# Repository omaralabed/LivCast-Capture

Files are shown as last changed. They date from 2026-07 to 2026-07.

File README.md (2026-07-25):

# LivCast Capture

Compact **CM5** HDMI/SDI capture box for **Livcast-iOS** on iPhone.

Camera in → on-box preview → USB-C **network video** to phone. Bonding is a separate product (**LivCast Bond**).

## Locked I/O

| Port | Direction | Job |
|---|---|-----|
| SDI in | In | Camera (BNC) |
| HDMI in | In | Camera |
| Input select | Software | HDMI **or** SDI (dual CSI bridges) |
| HDMI out | Out | Playback / external monitor |
| SDI out | Out | Playback / SDI deck |
| USB-C (phone) | Data + charge | Network video → iPhone; **box charges phone** |
| USB-C (power) | In | PD: wall charger or adapter |
| D-Tap | In | Camera battery power |
| 3.5" LCD | On box | SPI preview via 40-pin GPIO (Hosyond 480×320) |

## Locked ingest (best quality)

**Dual bridge — no SDI→HDMI hop:**

```
SDI in  ──► SDI RX ──► CSI bridge ──┐
                                    ├──► CM5 ──┬── USB-C data+charge ──► iPhone
HDMI in ──► HDMI→CSI ───────────────┘          ├── HDMI out ───────────► monitor
                                               ├── SDI out (playback) ─► SDI deck
                                               └── 40-pin SPI ─────────► 3.5" preview

SDI playback path (not input loop):
  CM5 HDMI TX ──► HDMI RX (parallel) ──► GS2962A ──► SDI BNC
```

Software picks which CSI stream is live (one input at a time). **SDI out mirrors HDMI playback** (GS2962A), not a reclocked loop of SDI in. **Phone port charges the iPhone**. **D-Tap + USB-C PD** power the box. No built-in battery.

## Why USB network, not UVC

iPhone does **not** expose UVC as `AVCaptureDevice.external` (that path is iPadOS). LivCast Capture presents as a USB Ethernet gadget and streams video over IP to Livcast-iOS.

## Format targets

Design for **720p / 1080i / 1080p** as a hard requirement. HDMI path uses **IT6616** (CSI interlaced). Livcast-iOS handles deinterlace.

## Repo

- Spec: [`docs/REQUIREMENTS.md`](docs/REQUIREMENTS.md)
- Chips: [`docs/CHIP_SHORTLIST.md`](docs/CHIP_SHORTLIST.md)
- Hardware: active sheet is a **block-diagram** schematic [`kicad/LivCast_Capture.kicad_sch`](kicad/LivCast_Capture.kicad_sch) (yellow boxes + few labeled nets; preview [`kicad/preview/LivCast_Capture_BLOCK.png`](kicad/preview/LivCast_Capture_BLOCK.png)). The dense auto-generated pin dump is archived as [`kicad/archive_sheets/LivCast_Capture_dense_pins.kicad_sch`](kicad/archive_sheets/LivCast_Capture_dense_pins.kicad_sch); older hierarchical sheets also under [`kicad/archive_sheets/`](kicad/archive_sheets/).
- Firmware: Linux CSI capture + USB gadget + IP video
- Phone: Livcast-iOS USB-network ingest (separate app repo)

## Related

- Hardware remote: https://github.com/omaralabed/LivCast-Capture
- Livcast-iOS: companion app (USB-net ingest required for iPhone path)
- LivCast Bond: multi-SIM uplink box (separate product)

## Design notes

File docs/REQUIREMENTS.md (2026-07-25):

# LivCast Capture — Requirements

**Schematic:** single file [`kicad/LivCast_Capture.kicad_sch`](../kicad/LivCast_Capture.kicad_sch) (open via `LivCast_Capture.kicad_pro`); archived multi-sheet hierarchy in [`kicad/archive_sheets/`](../kicad/archive_sheets/).
Status: **I/O + dual-bridge ingest locked** (2026-07-25).

## Product

CM5-based capture box: camera → Livcast-iOS on iPhone over USB-C network video. Separate from **LivCast Bond**.

Quality priority: **best video quality** — no SDI→HDMI conversion in the capture path.

## Locked signal path

```
SDI in  ──► SDI RX ──► CSI bridge ──┐
                                    ├──► CM5 ──┬── USB-C data ───► iPhone
HDMI in ──► HDMI→CSI ───────────────┘          ├── HDMI out ─────► monitor
                                               ├── SDI out ──────► SDI deck
                                               └── 40-pin SPI ───► 3.5" preview

Power:  USB-C PD in (wall charger or D-Tap→USB-C adapter) ──► 5 V / 5 A rail
```

| Stage | Role |
|---|---|
| SDI RX | Equalize + deserialize SDI from BNC |
| CSI bridge (SDI) | Parallel / link → MIPI CSI-2 into CM5 |
| HDMI→CSI | HDMI → MIPI CSI-2 into CM5 |
| Input select | Software: arm one CSI path at a time |

**Rejected:** SDI→HDMI into a shared HDMI switch/bridge (extra hop, worse quality).

## Ports

| Port | Direction | Job |
|---|---|-----|
| SDI in | In | Camera (BNC) |
| HDMI in | In | Camera |
| Input select | Software | HDMI **or** SDI |
| HDMI out | Out | Playback / external monitor |
| SDI out | Out | Playback / SDI deck via **GS2962A** from CM5 HDMI mirror (**not** input loop) |
| USB-C (phone) | Data + charge | Network video → iPhone (**not** UVC); **box also charges the phone** |
| USB-C (power) | In | PD sink: wall charger **or** D-Tap on box / D-Tap→USB-C |
| D-Tap | In | Camera battery (~12–17 V) → same 5 V system rail |
| 3.5" LCD | On box | SPI preview via 40-pin GPIO (Hosyond 480×320) |

## Power (locked)

- **No** built-in lithium. **No** onboard NP-F pack (D-Tap is the camera-battery tap).
- **Inlets:** USB-C PD **and** D-Tap (either can power the box).
- **Phone USB-C:** USB gadget (network video) **and** PD **source** to charge the iPhone (PD power-role swap: phone stays data host, box supplies VBUS/PD).
- **Budget:**
  - Box alone: ~15 W typ / ~20–25 W peak
  - Plus iPhone charge: plan **+15–30 W**
  - **Input design ≥60 W** (D-Tap + PD sink); system rail **5 V / 5 A** for CM5 side; PD source path to phone
- **Two USB-C ports:** power-in vs phone (data + charge-out). D-Tap is a third power inlet.
- Camera / D-Tap battery runtime is the operator’s responsibility (no charge-throttle policy on the box).

## Constraints

- **SoC:** Raspberry Pi CM5 on custom carrier (Pi 5 OK for proto).
- **Ingest:** Dual bridge → CSI; one active input.
- **iPhone path:** USB Ethernet gadget + IP video. No UVC. Phone USB-C also **charges** the iPhone (box = PD source).
- **HDMI out:** Native CM5 HDMI TX.
- **SDI out:** Real playback via **IT66021FN** (HDMI RX parallel from CM5 HDMI TX) → **GS2962A** → BNC — **not** Antmicro SDI-in reclocked loop.
- **Preview:** On-box 3.5" SPI; HDMI/SDI out for real monitoring.

## Format targets

| Format | Goal | Notes |
|---|---|---|
| 720p | Required | Hardware must pass; iOS handles display/encode path |
| 1080p | Required | Hardware must pass; lock fps later (25/30/50/60) |
| 1080i | Required | Silicon must support interlaced CSI/SDI; **deinterlace on Livcast-iOS** |

**Split:** Box passes formats through. **Livcast-iOS** owns deinterlace / scale / encode.

**HDMI silicon:** **IT6616** (ITE) — datasheet **CSI interlaced mode**. **Do not use TC358743.**

Hardware must **accept and deliver** 720p, 1080i, and 1080p on both HDMI and SDI.

## Open hardware choices (locked)

**Locked** — see [`CHIP_SHORTLIST.md`](CHIP_SHORTLIST.md) for full table, alternates, and format notes.

Primary MPNs: **CM5** (eMMC); **IT6616** (HDMI→CSI0, **CSI interlaced**); **GS2971A** + **LIF-MD6000-6JMG80I** CrossLink (SDI→CSI1, Antmicro sch); **IT66021FN** + **GS2962A** (SDI playback out from CM5 HDMI mirror; **GS2989** optional dual drive); **TPS25751** (PD sink ≥60 W + phone PD source); **LM76003** + **TPS62130A**; **TPS25947**; Hosyond 3.5" SPI LCD. **Rejected:** TC358743.

## Software split

| Side | Job |
|---|-----|
| Box (Linux) | Dual CSI capture, input select, packetize, USB gadget, SPI UI — pass formats through |
| Livcast-iOS | USB-net ingest; **format handling** (deinterlace / scale); Livcast uplink |

## Non-goals (this product)

- Multi-SIM bonding (→ LivCast Bond)
- UVC to iPhone
- SDI→HDMI in the capture path
- Dual simultaneous HDMI+SDI streaming (select one)
- Built-in battery / onboard NP-F pack
- Powering the **box** from the iPhone (phone is charged **by** the box, not the reverse)
- Shipping Antmicro-style SDI **input loop** (J2/GS2988) as the only / product **SDI out**

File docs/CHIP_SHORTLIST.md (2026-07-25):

# LivCast Capture — Chip Shortlist (Rev A)

Status: **Rev A picks locked** (2026-07-25).  
Priority: **guaranteed** 720p / **1080i** / 1080p on **both** HDMI and SDI (best quality, dual CSI).

Reference designs:
- **Antmicro SDI→MIPI CSI bridge** (golden SDI path): [openhardware portal](https://openhardware.antmicro.com/boards/sdi-mipi-bridge/) · [GitHub](https://github.com/antmicro/sdi-mipi-bridge-hw) · local copy [`refs/antmicro-sdi-mipi-bridge/`](../refs/antmicro-sdi-mipi-bridge/) (KiCad + `doc/sdi-mipi-bridge.pdf`, Apache-2.0)
- **SDI ingest (Antmicro):** condensed on single schematic [`kicad/LivCast_Capture.kicad_sch`](../kicad/LivCast_Capture.kicad_sch); full GS2971A + CrossLink detail in [`kicad/archive_sheets/04_SDI_CSI.kicad_sch`](../kicad/archive_sheets/04_SDI_CSI.kicad_sch) + [`refs/antmicro-sdi-mipi-bridge/`](../refs/antmicro-sdi-mipi-bridge/). Antmicro **J2/GS2988 input-loop is NOT product SDI out**.
- **Flat sch:** Power (D-Tap/PD/bucks) + condensed **CM5_IO** + SDI playback symbols on `LivCast_Capture.kicad_sch`.
- **SDI playback out (required):** **GS2962A** — real symbols on single schematic `LivCast_Capture.kicad_sch` (SDI PLAYBACK OUT region; from archived `07_SDI_OUT`): HDMI 1:2 buffer → **IT66021FN** → parallel → **GS2962A** → BNC; **GS2989 not required** (integrated cable driver)
- ITE **IT6616** HDMI→CSI (datasheet: **interlaced mode in CSI**)
- Prior Livcast adapter BOM for Semtech SDI + TI power (UVC path rejected)

**Rejected for production:** Toshiba **TC358743** — Pi-common, but **not** accepted here for solid 1080i.

---

## Rev A primary picks

| Block | MPN | Mfr | Role |
|---|-----|-----|---|
| SoC | **CM5** (eMMC) | Raspberry Pi | Capture, encode, USB gadget, SPI UI, HDMI TX |
| HDMI → CSI | **IT6616** | ITE | HDMI 1.4 → MIPI CSI-2 (CAM0); **CSI interlaced mode supported** |
| SDI RX | **GS2971A** | Semtech | 3G-SDI EQ + deserialize + reclock (10-bit 4:2:2 parallel) |
| SDI → CSI | **LIF-MD6000-6JMG80I** | Lattice CrossLink | Parallel → MIPI CSI-2 (CAM1); **copy Antmicro sch** |
| SDI out (ser) | **GS2962A** | Semtech | **Required** — 3G-SDI serializer for **playback** out (not input loop) |
| SDI cable driver | **Not required** (GS2962A integrated CD on flat sch) | Semtech | GS2989 only if dual/external drive needed |
| HDMI tap for SDI out | **IT66021FN** (or equiv. HDMI RX) | ITE | Parallel from **CM5 HDMI TX** mirror → GS2962A |
| USB-C PD (power in) | **TPS25751D** | TI | PD **sink** ≥60 W → system VIN |
| USB-C PD (phone) | **TPS25751S/D** | TI | PD **source** + data **UFP** (gadget); charge iPhone |
| VIN buck | **LM76003** (or TPS54560) | TI | D-Tap / PD VIN → **5 V / ≥5 A** |
| 3V3 buck | **TPS62130A** | TI | 5 V → 3V3 |
| Bridge rails | per DS | TI LDOs/bucks | GS2971A / CrossLink / IT6616 |
| eFuse (phone VBUS) | **TPS25947** | TI | Phone charge path |
| Display | Hosyond **3.5" 480×320 SPI** | — | 40-pin GPIO |

### Alternates (supply only — same format contract)

| Block | Alternate | Notes |
|---|---|---|
| HDMI → CSI | **IT6625** | HDMI 2.0; also **CSI interlaced mode** in ITE docs |
| HDMI → CSI (symmetric) | **IT66021FN** → parallel → CrossLink | Same CSI bridge style as SDI; use if IT6616 NDA/availability blocks |
| SDI → CSI | CrossLink-NX **LIFCL-40** | More headroom |
| SDI RX | GS2961A + external EQ | If GS2971A unavailable |
| PD | TPS25750 | Fallback |

---

## Signal map (locked)

```
HDMI in ──► IT6616 ──────────────────► CSI0 ──► CM5 ──┬── USB-C data+charge ──► iPhone
SDI in  ──► GS2971A ──► CrossLink ──► CSI1 ──► CM5 ──┤
                                                     ├── HDMI TX ──┬──► HDMI out (monitor)
                                                     │             └──► IT66021FN ──► GS2962A ──► SDI out (playback)
                                                     └── SPI ──► 3.5" preview

Power: D-Tap and/or USB-C PD in ──► 5V0
```

Software selects **CSI0 or CSI1** (one live input).

**SDI out = playback** (same program as HDMI out from CM5), **not** a reclocked loop of SDI in.  
Antmicro J2/GS2988 loop may stay in `archive_sheets/04` for debug only — **do not ship as the product SDI out.**

---

## Format support (locked requirement)

| Format | HDMI (**IT6616**) | SDI (GS2971A + CrossLink) |
|---|---|---|
| 720p | Required / supported | Required / SMPTE |
| 1080p | Required / supported | Required / 3G-SDI |
| 1080i | Required — **IT6616 CSI interlaced mode** | Required / SMPTE; iOS deinterlaces |

No “bench risk” language on the primary HDMI part — format set is a **hard product requirement**. Bring-up still verifies firmware/EDID, but silicon choice is made for interlaced CSI.

---

## Why not TC358743

Common on Pi HATs; weak / non-guaranteed 1080i story for production. **Do not use** on LivCast Capture Rev A.

---

## Power parts detail

| Rail | Source | Target |
|---|---|---|
| VIN | D-Tap (~12–17 V) and/or USB-C PD sink (9–20 V) | OR’d into buck |
| 5V0 | LM76003 | CM5 + loads; ≥5 A |
| Phone VBUS | TPS25751 + eFuse | Charge iPhone |
| 3V3 / 1V8 / 1V2 / … | From 5V0 | Per video IC DS |

No internal battery. Operator owns camera-battery runtime.

---

## Connectors

| Ref | Part | Function |
|-----|---|---|
| J_HDMI_IN | HDMI Type-A | Camera HDMI |
| J_HDMI_OUT | HDMI Type-A / Micro | Monitor |
| J_SDI_IN | HD-BNC 75 Ω | Camera SDI |
| J_SDI_OUT | HD-BNC 75 Ω | SDI deck |
| J_USBC_PWR | USB-C | PD power in |
| J_USBC_PHONE | USB-C | Data + PD charge out |
| J_DTAP | D-Tap | Camera battery in |
| J_LCD | 40-pin | Hosyond SPI |
| U_CM5 | CM5 | Compute Module 5 |

ESD: HDMI/USB TPD4E05U06-class; SDI per Semtech; D-Tap fuse + reverse protection.

---

## PCB notes

- Semtech 75 Ω SDI layout; GS2989 placement  
- MIPI length match CSI0/CSI1 → CM5  
- USB-C: PD + gadget data; USB2 minimum for ECM  
- Thermal: CM5 + GS2971A + CrossLink + IT6616  
- Suggest **6-layer**

---

## Bring-up (verification, not part-selection)

1. IT6616: 720p / 1080i / 1080p HDMI → CSI0  
2. GS2971A+CrossLink: same on SDI → CSI1  
3. TPS25751: phone charge + USB gadget  
4. LM76003: D-Tap / PD under box + phone charge load

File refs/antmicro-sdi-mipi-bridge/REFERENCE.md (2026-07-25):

# Antmicro SDI–MIPI Bridge — vendor reference

LivCast Capture overlay note (not part of Antmicro’s tree). Upstream clone lives in `sdi-mipi-bridge-hw/`.

LivCast `kicad/04_SDI_CSI.kicad_sch` now contains the adapted Antmicro schematic (title/company/CSI1+I2C globals).

## Links

- Product / board page: https://openhardware.antmicro.com/boards/sdi-mipi-bridge/
- Hardware repo: https://github.com/antmicro/sdi-mipi-bridge-hw
- License: **Apache-2.0** (see `sdi-mipi-bridge-hw/LICENSE`)

## Portal schematic PDF

Download from the openhardware “Schematic PDF” button often saves as **`undefined.pdf`** on Desktop (portal filename bug).

- Your file: `/Users/viewvision/Desktop/undefined.pdf`
- Title block: **SDI-MIPI Bridge**, Rev **1.3.4**, KiCad **9.0.7**, date **2023-10-12**, Antmicro Ltd.
- Same design as the git clone schematic; use either this PDF or `sdi-mipi-bridge-hw/*.kicad_sch`

Suggested rename:
`mv ~/Desktop/undefined.pdf ~/Desktop/SDI-MIPI-Bridge_schematic.pdf`

## LivCast Capture use

Used as **reference** for LivCast Capture sheet **04** (Semtech **GS2971A** + Lattice CrossLink **LIF-MD6000**).

We integrate this signal path onto the **CM5 carrier**, not as a standalone Antmicro daughterboard unless used for proto bring-up.

## Key files in clone

| Path | Notes |
|---|---|
| `sdi-mipi-bridge-hw/sdi-mipi-bridge.kicad_sch` | Single-sheet schematic (title: SDI-MIPI Bridge) |
| `sdi-mipi-bridge-hw/sdi-mipi-bridge.kicad_pcb` | PCB |
| `sdi-mipi-bridge-hw/doc/sdi-mipi-bridge.pdf` | Schematic PDF in repo |
| `sdi-mipi-bridge-hw/lib/` | Symbols, footprints, 3D models |

## Key ICs (from schematic MPN)

- **U2** — Semtech **GS2971A** (SDI deserializer)
- **U4** — Lattice CrossLink **LIF-MD6000-6JMG80I**

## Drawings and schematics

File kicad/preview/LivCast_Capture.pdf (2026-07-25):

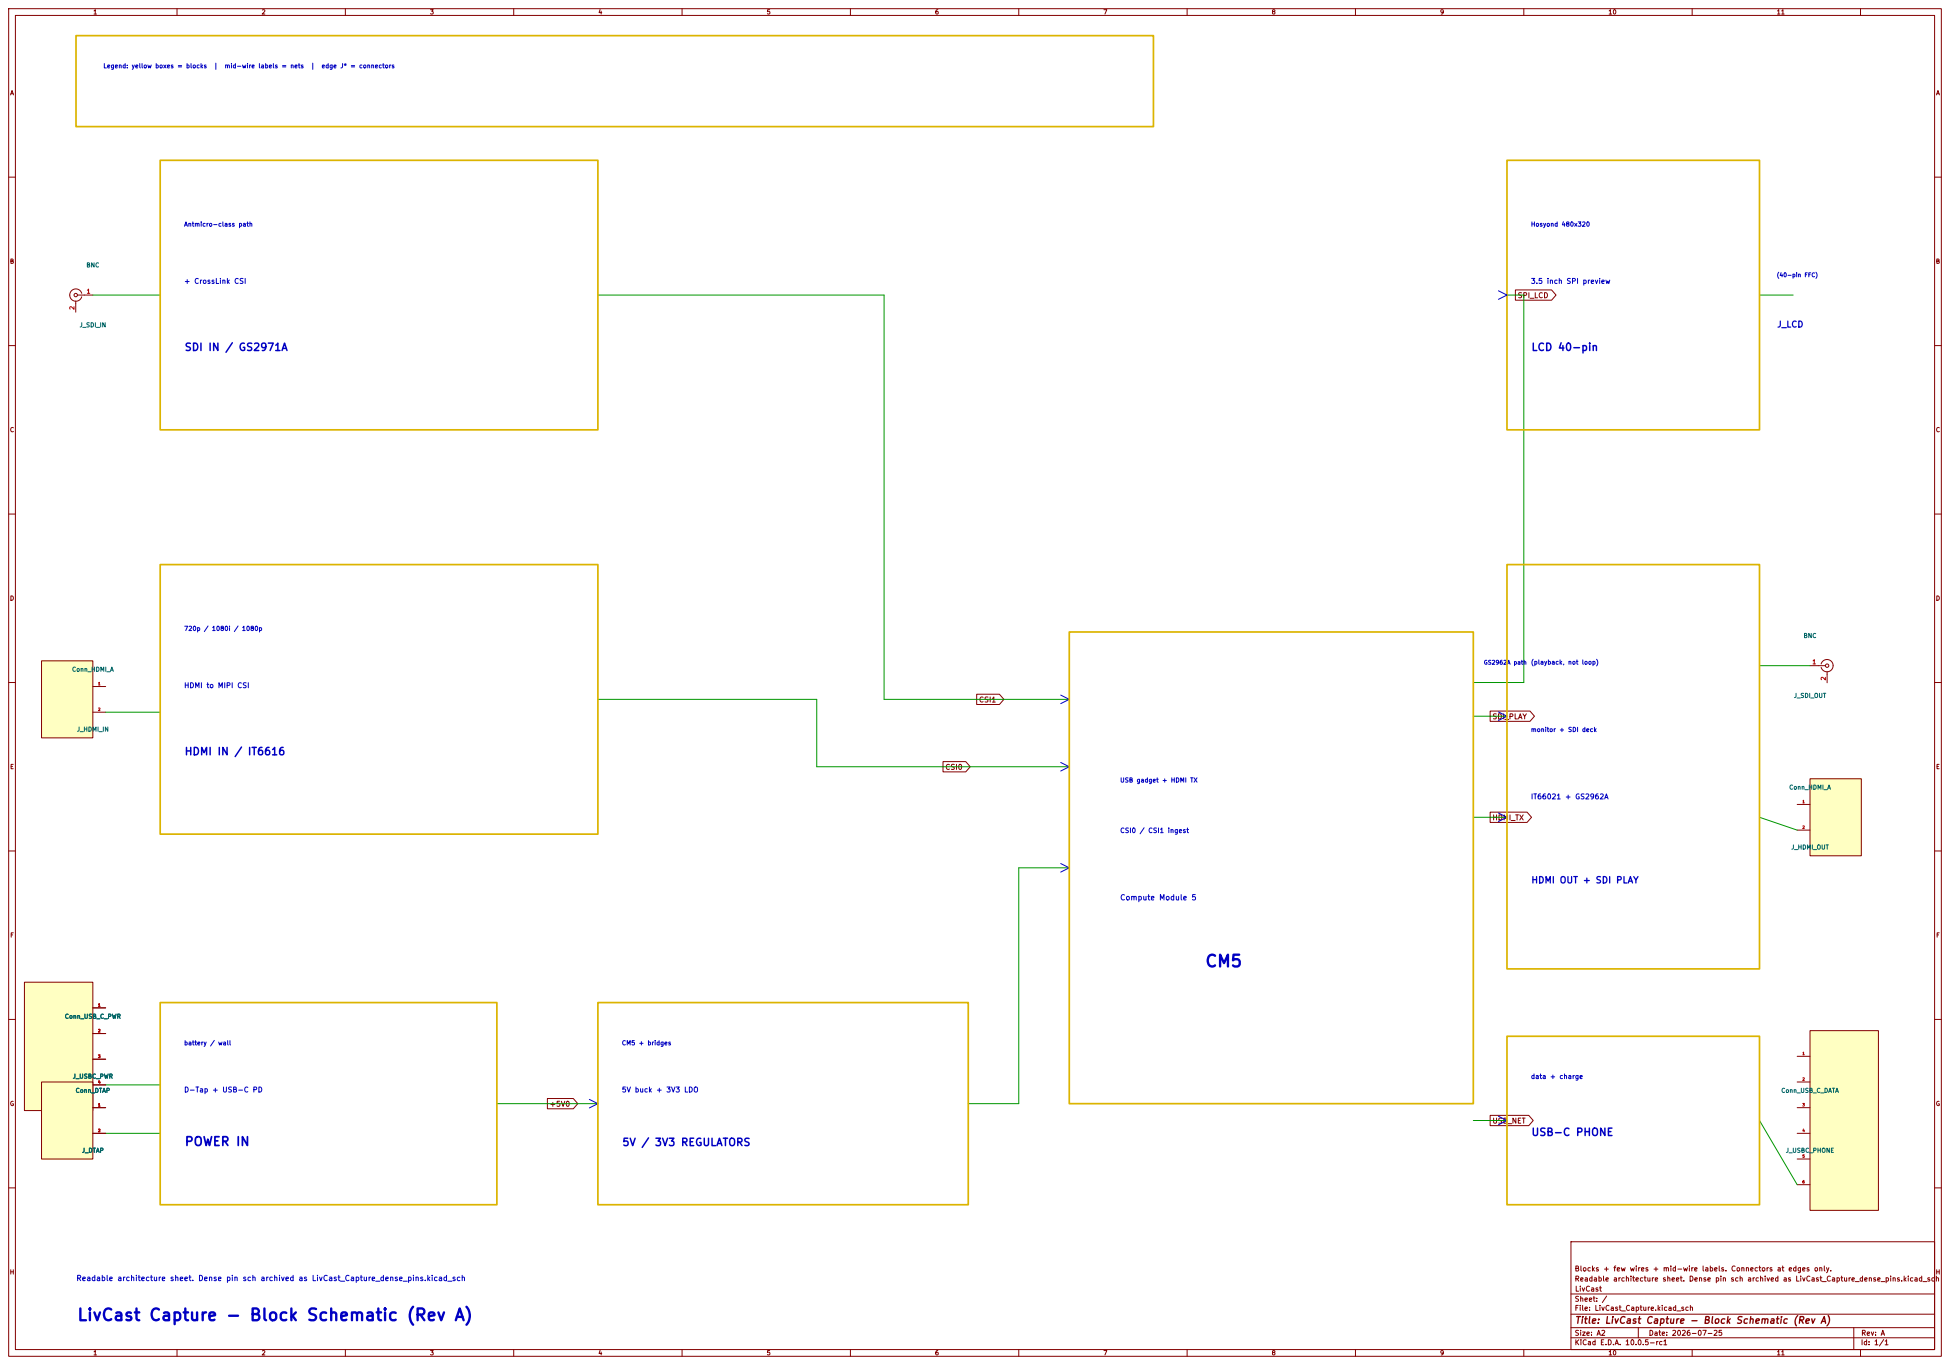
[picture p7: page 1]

Legend: yellow boxes = blocks | mid-wire labels = nets | edge J* = connectors Antmicro-class path

(playback, not loop) + CrossLink CSI

battery / wall HDMI IN / IT6616

HDMI to MIPI CSI

CSI0 / CSI1 ingest USB gadget + HDMI TX

HDMI OUT + SDI PLAY

Blocks + few wires + mid-wire labels. Connectors at edges only.
Readable architecture sheet. Dense pin sch archived as LivCast_Capture_dense_pins.kicad_sch
LivCast
Sheet: /
File: LivCast_Capture.kicad_sch
Title: LivCast Capture - Block Schematic (Rev A)

LivCast Capture - Block Schematic (Rev A)

Size: A2 | Rev: A
KiCad E.D.A. 10.0.5-rc1 | Id: 1/1

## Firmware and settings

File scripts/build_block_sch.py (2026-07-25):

#!/usr/bin/env python3
"""Generate a readable A2 landscape block-diagram schematic (no pin dumps)."""
from __future__ import annotations

import re
import subprocess
import uuid
from pathlib import Path

ROOT = Path(__file__).resolve().parents[1] / "kicad"
SCH = ROOT / "LivCast_Capture.kicad_sch"
LIB = ROOT / "libs/livcast-capture/livcast-capture.kicad_sym"
BNC_LIB = ROOT / "libs/antmicro-sdi-mipi/sdi-mipi-bridge.kicad_sym"
KICAD = Path("/Applications/KiCad/KiCad.app/Contents/MacOS/kicad-cli")
PREVIEW = ROOT / "preview"


def uid() -> str:
    return str(uuid.uuid4())


def extract_symbol(text: str, name: str) -> str:
    token = f'(symbol "{name}"'
    i = text.find(token)
    if i < 0:
        raise SystemExit(f"missing symbol {name}")
    depth = 0
    for j in range(i, len(text)):
        if text[j] == "(":
            depth += 1
        elif text[j] == ")":
            depth -= 1
            if depth == 0:
                return text[i : j + 1]
    raise SystemExit(f"unclosed {name}")


def prefix_lib(chunk: str, lib: str, name: str) -> str:
    """Rewrite (symbol \"Name\" -> (symbol \"lib:Name\" for sch embedding."""
    return chunk.replace(f'(symbol "{name}"', f'(symbol "{lib}:{name}"', 1)


def parse_pins(chunk: str) -> list[dict]:
    pins = []
    for m in re.finditer(
        r'\(pin (\w+) \w+\s*\(at ([-\d.]+) ([-\d.]+) (\d+)\)\s*\(length [-\d.]+\)\s*'
        r'\(name "([^"]+)"[\s\S]*?\(number "([^"]+)"',
        chunk,
    ):
        etype, x, y, rot, pname, pnum = m.groups()
        pins.append(
            {
                "etype": etype,
                "x": float(x),
                "y": float(y),
                "rot": int(rot),
                "name": pname,
                "num": pnum,
            }
        )
    return pins


def compact_hdmi_symbol(arch_text: str) -> tuple[str, list[dict]]:
    """Clone a known-good small connector (DTAP) as a 2-pin HDMI stub for the block sheet."""
    dtap = extract_symbol(arch_text, "livcast-capture:Conn_DTAP")
    hdmi = dtap.replace("livcast-capture:Conn_DTAP", "livcast-capture:Conn_HDMI_A", 1)
    hdmi = hdmi.replace("Conn_DTAP", "Conn_HDMI_A")
    # Rename pins for clarity in netlist
    hdmi = hdmi.replace('"VIN"', '"TMDS"').replace('"GND"', '"GND"')
    pins = parse_pins(hdmi)
    return hdmi, pins



def force_hide_pin_names(chunk: str) -> str:
    if re.search(r"\(pin_names\s*\n\s*\(hide yes\)", chunk) is None:
        if "(pin_names" in chunk:
            chunk = re.sub(
                r"\(pin_names(\s*\n\s*\(offset [-\d.]+\))?",
                "(pin_names\n\t\t(hide yes)\\1",
                chunk,
                count=1,
            )
        else:
            chunk = chunk.replace(
                '(exclude_from_sim',
                '(pin_names\n\t\t(hide yes)\n\t\t)\n\t\t(exclude_from_sim',
                1,
            )
    return chunk


class Sch:
    def __init__(self) -> None:
        self.embeds: list[str] = []
        self.items: list[str] = []
        self.pin_meta: dict[str, list[dict]] = {}

    def add_embed(self, chunk: str, lib_id: str, pins: list[dict]) -> None:
        self.embeds.append(chunk)
        self.pin_meta[lib_id] = pins

    def rect(self, x1: float, y1: float, x2: float, y2: float) -> None:
        # Yellow outline, empty fill — block diagram boxes
        self.items.append(
            f"""\t(rectangle
\t\t(start {x1:g} {y1:g})
\t\t(end {x2:g} {y2:g})
\t\t(stroke
\t\t\t(width 0.508)
\t\t\t(type default)
\t\t\t(color 220 180 0 1)
\t\t)
\t\t(fill
\t\t\t(type none)
\t\t)
\t\t(uuid "{uid()}")
\t)"""
        )

    def text(
        self,
        msg: str,
        x: float,
        y: float,
        size: float = 2.54,
        bold: bool = False,
        justify: str = "left bottom",
    ) -> None:
        bold_s = "\n\t\t\t\t(bold yes)" if bold else ""
        self.items.append(
            f"""\t(text "{msg}"
\t\t(exclude_from_sim no)
\t\t(at {x:g} {y:g} 0)
\t\t(effects
\t\t\t(font
\t\t\t\t(size {size:g} {size:g}){bold_s}
\t\t\t)
\t\t\t(justify {justify})
\t\t)
\t\t(uuid "{uid()}")
\t)"""
        )

    def wire(self, x1: float, y1: float, x2: float, y2: float) -> None:
        self.items.append(
            f"""\t(wire
\t\t(pts
\t\t\t(xy {x1:g} {y1:g}) (xy {x2:g} {y2:g})
\t\t)
\t\t(stroke
\t\t\t(width 0)
\t\t\t(type default)
\t\t)
\t\t(uuid "{uid()}")
\t)"""
        )

    def polyline(self, pts: list[tuple[float, float]]) -> None:
        xy = " ".join(f"(xy {x:g} {y:g})" for x, y in pts)
        self.items.append(
            f"""\t(polyline
\t\t(pts
\t\t\t{xy}
\t\t)
\t\t(stroke
\t\t\t(width 0)
\t\t\t(type default)
\t\t)
\t\t(uuid "{uid()}")
\t)"""
        )

    def glabel(
        self,
        name: str,
        x: float,
        y: float,
        shape: str = "bidirectional",
        rot: int = 0,
        justify: str = "left",
        size: float = 1.524,
    ) -> None:
        self.items.append(
            f"""\t(global_label "{name}"
\t\t(shape {shape})
\t\t(at {x:g} {y:g} {rot})
\t\t(effects
\t\t\t(font
\t\t\t\t(size {size:g} {size:g})
\t\t\t)
\t\t\t(justify {justify})
\t\t)
\t\t(uuid "{uid()}")
\t\t(property "Intersheetrefs" "${{INTERSHEET_REFS}}"
\t\t\t(at {x:g} {y:g} 0)
\t\t\t(hide yes)
\t\t\t(effects
\t\t\t\t(font
\t\t\t\t\t(size 1.27 1.27)
\t\t\t\t)
\t\t\t)
\t\t)
\t)"""
        )

    def place(
        self,
        lib_id: str,
        ref: str,
        value: str,
        x: float,
        y: float,
        rot: int = 0,
        mirror: str | None = None,
    ) -> dict[str, tuple[float, float]]:
        """Place symbol; return pin absolute positions {num: (x,y)}."""
        pins = self.pin_meta[lib_id]
        pin_uuids = "\n".join(
            f'\t\t(pin "{p["num"]}"\n\t\t\t(uuid "{uid()}")\n\t\t)' for p in pins
        )
        mir = f'\n\t\t(mirror {mirror})' if mirror else ""
        self.items.append(
            f"""\t(symbol
\t\t(lib_id "{lib_id}")
\t\t(at {x:g} {y:g} {rot}){mir}
\t\t(unit 1)
\t\t(exclude_from_sim no)
\t\t(in_bom yes)
\t\t(on_board yes)
\t\t(dnp no)
\t\t(uuid "{uid()}")
\t\t(property "Reference" "{ref}"
\t\t\t(at {x:g} {y + 8.89:g} 0)
\t\t\t(effects
\t\t\t\t(font
\t\t\t\t\t(size 1.27 1.27)
\t\t\t\t)
\t\t\t)
\t\t)
\t\t(property "Value" "{value}"
\t\t\t(at {x:g} {y - 8.89:g} 0)
\t\t\t(effects
\t\t\t\t(font
\t\t\t\t\t(size 1.27 1.27)
\t\t\t\t)
\t\t\t)
\t\t)
\t\t(property "Footprint" ""
\t\t\t(at {x:g} {y:g} 0)
\t\t\t(hide yes)
\t\t\t(effects
\t\t\t\t(font
\t\t\t\t\t(size 1.27 1.27)
\t\t\t\t)
\t\t\t)
\t\t)
{pin_uuids}
\t)"""
        )
        # Absolute pin positions (no rotation support beyond 0/180 for our uses)
        abs_pins: dict[str, tuple[float, float]] = {}
        for p in pins:
            px, py = p["x"], p["y"]
            if rot == 180:
                px, py = -px, -py
            elif rot == 90:
                px, py = -py, px
            elif rot == 270:
                px, py = py, -px
            if mirror == "x":
                py = -py
            elif mirror == "y":
                px = -px
            abs_pins[p["num"]] = (x + px, y + py)
        return abs_pins

    def link_h(
        self,
        x1: float,
        y: float,
        x2: float,
        label: str | None = None,
        shape: str = "bidirectional",
    ) -> None:
        """Horizontal wire with optional mid global label."""
        self.wire(x1, y, x2, y)
        if label:
            mx = (x1 + x2) / 2
            # Point label left if wire goes left-to-right
            self.glabel(label, mx, y, shape=shape, rot=0, justify="left")

    def arrow_tip(self, x: float, y: float, facing: str = "right") -> None:
        """Small polyline arrow head at end of a link."""
        if facing == "right":
            self.polyline([(x - 2.54, y + 1.27), (x, y), (x - 2.54, y - 1.27)])
        elif facing == "left":
            self.polyline([(x + 2.54, y + 1.27), (x, y), (x + 2.54, y - 1.27)])
        elif facing == "up":
            self.polyline([(x - 1.27, y - 2.54), (x, y), (x + 1.27, y - 2.54)])
        else:
            self.polyline([(x - 1.27, y + 2.54), (x, y), (x + 1.27, y + 2.54)])

    def write(self) -> None:
        parts = [
            "(kicad_sch",
            "\t(version 20250114)",
            '\t(generator "livcast_block")',
            '\t(generator_version "9.0")',
            f'\t(uuid "{uid()}")',
            '\t(paper "A2")',
            "\t(title_block",
            '\t\t(title "LivCast Capture - Block Schematic (Rev A)")',
            '\t\t(date "2026-07-25")',
            '\t\t(rev "A")',
            '\t\t(company "LivCast")',
            '\t\t(comment 1 "Readable architecture sheet. Dense pin sch archived as LivCast_Capture_dense_pins.kicad_sch")',
            '\t\t(comment 2 "Blocks + few wires + mid-wire labels. Connectors at edges only.")',
            "\t)",
            "\t(lib_symbols",
        ]
        parts.extend(self.embeds)
        parts.append("\t)")
        parts.extend(self.items)
        parts += [
            "\t(sheet_instances",
            '\t\t(path "/"',
            '\t\t\t(page "1")',
            "\t\t)",
            "\t)",
            "\t(embedded_fonts no)",
            ")",
        ]
        text = "\n".join(parts) + "\n"
        assert text.count("(") == text.count(")"), (
            text.count("("),
            text.count(")"),
        )
        SCH.write_text(text)
        print(f"Wrote {SCH} ({SCH.stat().st_size} bytes)")


def load_embeds(sch: Sch) -> None:
    lib = LIB.read_text()
    for name in ["Conn_DTAP", "Conn_USB_C_PWR", "Conn_USB_C_DATA"]:
        raw = extract_symbol(lib, name)
        # Upgrade path: use already-upgraded from dense sch if present
        chunk = force_hide_pin_names(prefix_lib(raw, "livcast-capture", name))
        # Prefer KiCad-expanded form from dense archive if available
        arch = (ROOT / "archive_sheets" / "LivCast_Capture_dense_pins.kicad_sch").read_text()
        token = f'(symbol "livcast-capture:{name}"'
        if token in arch:
            chunk = force_hide_pin_names(extract_symbol(arch, f"livcast-capture:{name}"))
        pins = parse_pins(chunk)
        if not pins:
            raise SystemExit(f"no pins for {name}")
        sch.add_embed(chunk, f"livcast-capture:{name}", pins)

    arch = (ROOT / "archive_sheets" / "LivCast_Capture_dense_pins.kicad_sch").read_text()

    # Compact HDMI stub (DTAP-sized) — full 14-pin body is unreadable on a block sheet
    hdmi, hpins = compact_hdmi_symbol(arch)
    sch.add_embed(hdmi, "livcast-capture:Conn_HDMI_A", hpins)

    # BNC from dense sch (already upgraded)
    bnc_id = "sdi-mipi-bridge:Conn_BNC_031-70526-21"
    bnc = force_hide_pin_names(extract_symbol(arch, bnc_id))
    bpins = parse_pins(bnc)
    if not bpins:
        raise SystemExit("no BNC pins")
    sch.add_embed(bnc, bnc_id, bpins)


def build_layout(sch: Sch) -> None:
    """
    A2 landscape 594 x 420 mm. Origin bottom-left, Y up.
    """
    # ---- Title / note ----
    sch.text(
        "LivCast Capture - Block Schematic (Rev A)",
        30,
        400,
        size=3.5,
        bold=True,
        justify="left bottom",
    )
    sch.text(
        "Readable architecture sheet. Dense pin sch archived as LivCast_Capture_dense_pins.kicad_sch",
        30,
        388,
        size=1.6,
        justify="left bottom",
    )

    # ---- Blocks (yellow empty rectangles) ----
    # POWER IN
    sch.rect(55, 305, 155, 365)
    sch.text("POWER IN", 62, 348, size=2.6, bold=True)
    sch.text("D-Tap + USB-C PD", 62, 332, size=1.5)
    sch.text("battery / wall", 62, 318, size=1.3)

    # REGULATORS
    sch.rect(185, 305, 295, 365)
    sch.text("5V / 3V3 REGULATORS", 192, 348, size=2.2, bold=True)
    sch.text("5V buck + 3V3 LDO", 192, 332, size=1.5)
    sch.text("CM5 + bridges", 192, 318, size=1.3)

    # CM5
    sch.rect(325, 195, 445, 335)
    sch.text("CM5", 365, 295, size=3.5, bold=True, justify="left bottom")
    sch.text("Compute Module 5", 340, 275, size=1.6, justify="left bottom")
    sch.text("CSI0 / CSI1 ingest", 340, 255, size=1.4, justify="left bottom")
    sch.text("USB gadget + HDMI TX", 340, 240, size=1.3, justify="left bottom")

    # HDMI IN / IT6616
    sch.rect(55, 175, 185, 255)
    sch.text("HDMI IN / IT6616", 62, 232, size=2.2, bold=True)
    sch.text("HDMI to MIPI CSI", 62, 212, size=1.5)
    sch.text("720p / 1080i / 1080p", 62, 195, size=1.3)

    # SDI IN / GS2971A + CrossLink
    sch.rect(55, 55, 185, 135)
    sch.text("SDI IN / GS2971A", 62, 112, size=2.2, bold=True)
    sch.text("+ CrossLink CSI", 62, 92, size=1.5)
    sch.text("Antmicro-class path", 62, 75, size=1.3)

    # HDMI OUT + SDI PLAYBACK
    sch.rect(455, 175, 530, 295)
    sch.text("HDMI OUT + SDI PLAY", 462, 270, size=1.9, bold=True)
    sch.text("IT66021 + GS2962A", 462, 245, size=1.5)
    sch.text("monitor + SDI deck", 462, 225, size=1.3)
    sch.text("(playback, not loop)", 462, 205, size=1.3)

    # USB-C PHONE
    sch.rect(455, 315, 530, 365)
    sch.text("USB-C PHONE", 462, 345, size=2.2, bold=True)
    sch.text("data + charge", 462, 328, size=1.4)

    # LCD
    sch.rect(455, 55, 530, 135)
    sch.text("LCD 40-pin", 462, 112, size=2.2, bold=True)
    sch.text("3.5 inch SPI preview", 462, 92, size=1.5)
    sch.text("Hosyond 480x320", 462, 75, size=1.3)

    # ---- Edge connectors ----
    dtap = sch.place(
        "livcast-capture:Conn_DTAP", "J_DTAP", "Conn_DTAP", 35, 340, mirror="y"
    )
    usbp = sch.place(
        "livcast-capture:Conn_USB_C_PWR",
        "J_USBC_PWR",
        "Conn_USB_C_PWR",
        35,
        318,
        mirror="y",
    )
    hdmi_in = sch.place(
        "livcast-capture:Conn_HDMI_A",
        "J_HDMI_IN",
        "Conn_HDMI_A",
        35,
        215,
        mirror="y",
    )
    sdi_in = sch.place(
        "sdi-mipi-bridge:Conn_BNC_031-70526-21",
        "J_SDI_IN",
        "BNC",
        35,
        95,
        mirror="y",
    )

    # Place just left of page edge so body stays on A2 (594mm)
    usbc = sch.place(
        "livcast-capture:Conn_USB_C_DATA",
        "J_USBC_PHONE",
        "Conn_USB_C_DATA",
        545,
        340,
    )
    hdmi_out = sch.place(
        "livcast-capture:Conn_HDMI_A",
        "J_HDMI_OUT",
        "Conn_HDMI_A",
        545,
        250,
    )
    sdi_out = sch.place(
        "sdi-mipi-bridge:Conn_BNC_031-70526-21",
        "J_SDI_OUT",
        "BNC",
        545,
        205,
    )

    sch.text("J_LCD", 535, 105, size=1.8, bold=True, justify="left bottom")
    sch.text("(40-pin FFC)", 535, 90, size=1.2, justify="left bottom")

    # ---- Connector wires ----
    px, py = dtap["1"]
    sch.wire(px, py, 55, py)
    px, py = usbp["1"]
    sch.wire(px, py, 55, py)
    px, py = hdmi_in["1"]
    sch.wire(px, py, 55, py)
    bnc_pin = next(iter(sdi_in))
    px, py = sdi_in[bnc_pin]
    sch.wire(px, py, 55, 95)

    px, py = usbc["1"]
    sch.wire(530, 340, px, py)
    px, py = hdmi_out["1"]
    sch.wire(530, 250, px, py)
    bnc_pin = next(iter(sdi_out))
    px, py = sdi_out[bnc_pin]
    sch.wire(530, 205, px, py)
    sch.wire(530, 95, 540, 95)

    # ---- Block links with mid labels ----
    sch.link_h(155, 335, 185, "+5V0", shape="output")
    sch.arrow_tip(185, 335, "right")

    sch.wire(295, 335, 310, 335)
    sch.wire(310, 335, 310, 265)
    sch.wire(310, 265, 325, 265)
    sch.arrow_tip(325, 265, "right")

    sch.link_h(445, 340, 455, "USB_NET", shape="output")
    sch.arrow_tip(455, 340, "right")

    sch.link_h(445, 250, 455, "HDMI_TX", shape="output")
    sch.arrow_tip(455, 250, "right")
    sch.link_h(445, 220, 455, "SDI_PLAY", shape="output")
    sch.arrow_tip(455, 220, "right")
    sch.text("GS2962A path", 448, 205, size=1.2)

    sch.wire(445, 210, 460, 210)
    sch.wire(460, 210, 460, 95)
    sch.link_h(460, 95, 455, "SPI_LCD", shape="output")
    sch.arrow_tip(455, 95, "right")

    sch.wire(185, 215, 250, 215)
    sch.wire(250, 215, 250, 235)
    sch.link_h(250, 235, 325, "CSI0", shape="output")
    sch.arrow_tip(325, 235, "right")

    sch.wire(185, 95, 270, 95)
    sch.wire(270, 95, 270, 215)
    sch.link_h(270, 215, 325, "CSI1", shape="output")
    sch.arrow_tip(325, 215, "right")

    sch.rect(30, 18, 350, 45)
    sch.text(
        "Legend: yellow boxes = blocks  |  mid-wire labels = nets  |  edge J* = connectors",
        38,
        28,
        size=1.3,
    )



def export_preview() -> None:
    PREVIEW.mkdir(parents=True, exist_ok=True)
    pdf = PREVIEW / "LivCast_Capture.pdf"
    png = PREVIEW / "LivCast_Capture_BLOCK.png"
    zoom = PREVIEW / "LivCast_Capture_ZOOM.png"
    # PDF
    subprocess.run(
        [
            str(KICAD),
            "sch",
            "export",
            "pdf",
            "-o",
            str(pdf),
            "--no-background-color",
            str(SCH),
        ],
        check=True,
    )
    print(f"PDF → {pdf}")
    # Full-page PNG via pdf plot pages as SVG then… use sch export svg + convert, or pdfium
    # KiCad 10: sch export svg
    svg_dir = PREVIEW / "_svg"
    svg_dir.mkdir(exist_ok=True)
    subprocess.run(
        [
            str(KICAD),
            "sch",
            "export",
            "svg",
            "-o",
            str(svg_dir),
            "--no-background-color",
            str(SCH),
        ],
        check=True,
    )
    svgs = list(svg_dir.glob("*.svg"))
    print("SVGs", svgs)
    # Rasterize with qlmanage or rsvg or magick
    # Rasterize PDF (full page, readable)
    import shutil

    tmp_prefix = PREVIEW / "LivCast_Capture_BLOCK_tmp"
    subprocess.run(
        ["pdftoppm", "-png", "-r", "150", str(pdf), str(tmp_prefix)],
        check=True,
    )
    page = Path(str(tmp_prefix) + "-1.png")
    if not page.exists():
        pages = list(PREVIEW.glob("LivCast_Capture_BLOCK_tmp*.png"))
        if not pages:
            raise SystemExit("pdftoppm produced no PNG")
        page = pages[0]
    shutil.move(str(page), str(png))
    subprocess.run(
        ["pdftoppm", "-png", "-r", "200", str(pdf), str(PREVIEW / "LivCast_Capture_ZOOM_tmp")],
        check=True,
    )
    zpage = PREVIEW / "LivCast_Capture_ZOOM_tmp-1.png"
    if zpage.exists():
        shutil.move(str(zpage), str(zoom))
    else:
        shutil.copy2(png, zoom)
    print(f"PNG → {png} and {zoom}")
    # Netlist (sparse OK)
    net = PREVIEW / "LivCast_Capture.net"
    try:
        subprocess.run(
            [str(KICAD), "sch", "export", "netlist", "-o", str(net), str(SCH)],
            check=True,
        )
        print(f"Netlist → {net} OK")
    except subprocess.CalledProcessError as e:
        print("Netlist failed", e)
        raise


def main() -> None:
    sch = Sch()
    load_embeds(sch)
    build_layout(sch)
    sch.write()
    export_preview()


if __name__ == "__main__":
    main()

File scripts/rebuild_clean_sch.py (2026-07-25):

#!/usr/bin/env python3
"""Rebuild livcast-capture symbols + sparse schematic (KiCad 9/10)."""
from __future__ import annotations

import re
import subprocess
import uuid
from pathlib import Path

ROOT = Path(__file__).resolve().parents[1] / "kicad"
LIB_PATH = ROOT / "libs/livcast-capture/livcast-capture.kicad_sym"
SCH_PATH = ROOT / "LivCast_Capture.kicad_sch"
BNC_LIB = ROOT / "libs/antmicro-sdi-mipi/sdi-mipi-bridge.kicad_sym"
KICAD = Path("/Applications/KiCad/KiCad.app/Contents/MacOS/kicad-cli")

PITCH = 7.62
PIN_LEN = 3.81
STUB = 12.7
STUB_LONG = 25.4
LABEL_PITCH = 15.24
PLAY_GAP = 160.0
PLAY_Y = 300.0


def uid() -> str:
    return str(uuid.uuid4())


def y_for(i: int, n: int) -> float:
    if n <= 1:
        return 0.0
    return (n - 1) * PITCH / 2 - i * PITCH


def pin_sexpr(etype: str, name: str, number: str, x: float, y: float, rot: int) -> str:
    return (
        f"      (pin {etype} line (at {x:g} {y:g} {rot}) (length {PIN_LEN})\n"
        f'        (name "{name}" (effects (font (size 1.0 1.0))))\n'
        f'        (number "{number}" (effects (font (size 0.8 0.8))))\n'
        f"      )"
    )


def make_symbol(
    name: str,
    mpn: str,
    left: list[tuple[str, str, str]],
    right: list[tuple[str, str, str]],
    width: float = 38.1,
    ref: str = "U",
) -> tuple[str, dict]:
    nL, nR = len(left), len(right)
    nmax = max(nL, nR, 1)
    h = (nmax - 1) * PITCH + 2 * PITCH
    cx = width / 2
    ytop = h / 2 + 2.54
    ybot = -h / 2 - 2.54
    lines: list[str] = []
    a = lines.append
    a(f'  (symbol "{name}" (in_bom yes) (on_board yes)')
    a("    (pin_names (offset 0.508) hide)")
    a(f'    (property "Reference" "{ref}" (id 0) (at {cx:g} {ytop:g} 0)')
    a("      (effects (font (size 1.27 1.27)))")
    a("    )")
    a(f'    (property "Value" "{name}" (id 1) (at {cx:g} {ybot:g} 0)')
    a("      (effects (font (size 1.27 1.27)))")
    a("    )")
    a(f'    (property "Footprint" "" (id 2) (at {cx:g} {ybot - 2.54:g} 0)')
    a("      (effects (font (size 1.27 1.27)) hide)")
    a("    )")
    a(f'    (property "Datasheet" "" (id 3) (at {cx:g} {ybot - 5.08:g} 0)')
    a("      (effects (font (size 1.27 1.27)) hide)")
    a("    )")
    a(f'    (property "MPN" "{mpn}" (id 4) (at {cx:g} {ybot - 3.81:g} 0)')
    a("      (effects (font (size 1.27 1.27)) hide)")
    a("    )")
    a(f'    (symbol "{name}_0_1"')
    a(f"      (rectangle (start 0 {-h / 2:g}) (end {width:g} {h / 2:g})")
    a("        (stroke (width 0.254) (type default))")
    a("        (fill (type background))")
    a("      )")
    a("    )")
    a(f'    (symbol "{name}_1_1"')
    pins: list[dict] = []
    for i, (etype, pname, pnum) in enumerate(left):
        y = y_for(i, nL)
        x = -PIN_LEN
        a(pin_sexpr(etype, pname, pnum, x, y, 0))
        pins.append({"name": pname, "num": pnum, "x": x, "y": y, "side": "left"})
    for i, (etype, pname, pnum) in enumerate(right):
        y = y_for(i, nR)
        x = width + PIN_LEN
        a(pin_sexpr(etype, pname, pnum, x, y, 180))
        pins.append({"name": pname, "num": pnum, "x": x, "y": y, "side": "right"})
    a("    )")
    a("  )")
    text = "\n".join(lines)
    assert text.count("(") == text.count(")"), name
    return text, {"name": name, "width": width, "height": h, "pins": pins}


def extract_symbol(text: str, name: str) -> str:
    token = f'(symbol "{name}"'
    i = text.find(token)
    if i < 0:
        raise SystemExit(f"missing symbol {name}")
    depth = 0
    for j in range(i, len(text)):
        ch = text[j]
        if ch == "(":
            depth += 1
        elif ch == ")":
            depth -= 1
            if depth == 0:
                chunk = text[i : j + 1]
                assert chunk.count("(") == chunk.count(")"), name
                return chunk
    raise SystemExit(f"unclosed symbol {name}")


def parse_pins_from_upgraded(chunk: str) -> list[dict]:
    pins = []
    # KiCad 10 expanded format
    for m in re.finditer(
        r'\(pin (\w+) line\s*\n\s*\(at ([-\d.]+) ([-\d.]+) (\d+)\)\s*\n\s*\(length [-\d.]+\)\s*\n'
        r'\s*\(name "([^"]+)"[\s\S]*?\(number "([^"]+)"',
        chunk,
    ):
        etype, x, y, rot, pname, pnum = m.groups()
        pins.append(
            {
                "etype": etype,
                "x": float(x),
                "y": float(y),
                "rot": int(rot),
                "name": pname,
                "num": pnum,
                "side": "left" if float(x) < 0 else "right",
            }
        )
    if pins:
        return pins
    # compact fallback
    for m in re.finditer(
        r'\(pin (\w+) line \(at ([-\d.]+) ([-\d.]+) (\d+)\) \(length [-\d.]+\)\s+'
        r'\(name "([^"]+)"[^\n]*\n\s+\(number "([^"]+)"',
        chunk,
    ):
        etype, x, y, rot, pname, pnum = m.groups()
        pins.append(
            {
                "etype": etype,
                "x": float(x),
                "y": float(y),
                "rot": int(rot),
                "name": pname,
                "num": pnum,
                "side": "left" if float(x) < 0 else "right",
            }
        )
    return pins


def force_hide_pin_names(chunk: str) -> str:
    """Ensure pin_names hide + per-name hide yes (KiCad 10 expanded)."""
    # pin_names block
    if "(pin_names" in chunk and "(hide yes)" not in chunk.split("(pin_names", 1)[1][:80]:
        chunk = chunk.replace(
            "(pin_names\n\t\t(offset",
            "(pin_names\n\t\t(hide yes)\n\t\t(offset",
            1,
        )
        chunk = chunk.replace("(pin_names hide)", "(pin_names hide)", 1)
    # Ensure (pin_names (hide yes)) style variants already ok
    if re.search(r"\(pin_names\s*\n\s*\(hide yes\)", chunk) is None:
        chunk = re.sub(
            r"\(pin_names(\s*\n\s*\(offset [-\d.]+\))?",
            "(pin_names\n\t\t(hide yes)\\1",
            chunk,
            count=1,
        )
    # Add (hide yes) under each (name ...) if missing
    def hide_name(m: re.Match) -> str:
        block = m.group(0)
        if "(hide yes)" in block:
            return block
        # insert before closing of name
        return block[:-1] + "\n\t\t\t\t\t(hide yes)\n\t\t\t\t)"

    chunk = re.sub(
        r'\(name "[^"]+"\s*\n(?:\t+\([^\n]*\)\s*\n)*?\t+\)',
        hide_name,
        chunk,
    )
    return chunk
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

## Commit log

2026-07-25 Initial LivCast Capture Rev A: dual-bridge CM5 capture box.
    Lock I/O, IT6616+GS2971A/CrossLink shortlist, power (D-Tap+PD+phone charge), KiCad block schematics, and Antmicro SDI-MIPI reference.
    [01_Power.kicad_sch, 02_CM5.kicad_sch, 03_HDMI_CSI.kicad_sch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]
2026-07-25 Add Antmicro SDI ingest sheet and real SDI playback out.
    Import GS2971A+CrossLink into sheet 04, require GS2962A playback path (not input loop), and lock IT6616 HDMI CSI.
    [02_CM5.kicad_sch, 04_SDI_CSI.kicad_sch, 07_SDI_OUT.kicad_sch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]
2026-07-25 Wire sheet 07 SDI playback path with real symbols.
    Add IT66021FN and GS2962A library symbols, TMDS 1:2 buffer to HDMI monitor and SDI out, and expand CM5 HDMI TMDS nets.
    [02_CM5.kicad_sch, 07_SDI_OUT.kicad_sch]
2026-07-25 Collapse KiCad design to a single schematic sheet.
    Archive hierarchical sheets; keep SDI playback symbols on one A1 overview with Antmicro detail referenced.
    [01_Power.kicad_sch, 02_CM5.kicad_sch, 03_HDMI_CSI.kicad_sch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]
2026-07-25 Fix schematic label overlap with wider pin pitch and IC spacing.
    Regenerate CM5/IT66021/GS2962/TMDS symbols at 3.81mm pitch, spread U701–U703 on A0, and realign nets so dense HDMI/CSI/VIDEO labels no longer collide.
    [LivCast_Capture.kicad_sch]
2026-07-25 Fix schematic layout: wire stubs, VIDEO bus, spaced ICs.
    Stop placing net labels on pin bodies; rebuild CM5 and SDI playback region for readability.
    [LivCast_Capture.kicad_sch]
2026-07-25 Simplify schematic symbols: hide pin names, split CM5, single VIDEO_BUS.
    Remove dense parallel pin stacks that made the sheet unreadable.
    [LivCast_Capture.kicad_sch]
2026-07-25 Redraw schematic with wire-only IC links and no stacked pin labels.
    Adjacent HDMI/SDI chips connect by wires; labels only on power and region exits.
    [LivCast_Capture.kicad_sch]
2026-07-25 Replace dense pin schematic with a readable block diagram.
    Archive the auto-generated pin dump; keep one clear architecture sheet.
    [LivCast_Capture.kicad_sch, LivCast_Capture_dense_pins.kicad_sch]
